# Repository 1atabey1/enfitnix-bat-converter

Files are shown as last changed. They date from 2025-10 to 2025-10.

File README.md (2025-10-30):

# ENFITNIX Battery Converter

Bike lights by Enfitnix use the quite common 18650 form factor for their batteries. However, they require a very specific protection PCB that exposes both poles of the battery in two concentric circles on one side.

It's kinda hard to get these batteries (at least in Europe -> over 30€ for a single [battery](https://de.grandado.com/products/enfitnix-navi800-fahrrad-licht-lg-3350mah-akku-integrierte-hohe-prazision-batterie)!!!), so this custom PCB offers the option of converting almost any 18650 battery into one that fits your bike light for a BOM cost of just around 1€.

## Order

Any non-basic part has an LCSC part number attached so you can directly upload the files from the latest [release](https://github.com/1atabey1/enfitnix-bat-converter/releases) to JLCPCB and order the fully assembled PCBs.

## Limitations

The current design is parametrised as follows

```
OVP: 4.2V
UVP: 2.5V
OCC: 18A
OCD: 40A
```

Before use, please confirm your cell's voltage range aligns with these limits (i.e. max cell operating voltage > OVP and min cell operating voltage < UVP). 

This will **not** work for LFP based cells!

## Usage

I recommend using heat shrink and a plastic base for the PCB as you get it from e.g. [AliExpress](https://de.aliexpress.com/item/32855964562.html)

With that the process is quite simple:
1. Solder one nickel strip each to the pads marked with + and -
2. Thread nickel strips through plastic base
3. Spot weld respective strips to their corresponding terminal of the cell
4. Wrap it all up in heat shrink

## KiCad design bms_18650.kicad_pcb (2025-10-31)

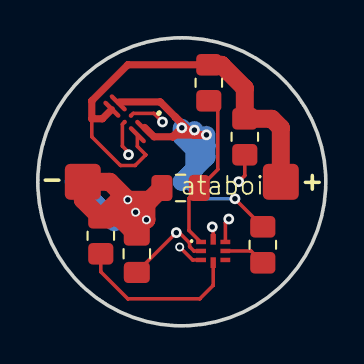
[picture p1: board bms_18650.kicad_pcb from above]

Board: 4 copper layers, 16.0 x 16.0 mm, 10 parts (0 on the bottom side), 9 nets.

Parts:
C1, C2: 0.1uF; C_0805_2012Metric_Pad1.18x1.45mm_HandSolder
IC1: BQ298218RUGR; ADS7056IRUGR
IC2: EFC8811R-TF; EFC8811RTF
J1: ENFITNIX_BAT
J2: CELL_LEAD_CONN
R3: 330; R_0805_2012Metric_Pad1.20x1.40mm_HandSolder
R4: 20; R_0805_2012Metric_Pad1.20x1.40mm_HandSolder
R5: 2k; R_0805_2012Metric_Pad1.20x1.40mm_HandSolder
R_SEN1: 0.001; R_0805_2012Metric_Pad1.20x1.40mm_HandSolder

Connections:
CELL+: IC2.4 (S2_1), IC2.6 (S2_2), J2.1 (CELL+), R3.2, R4.2
CELL-: C1.2, C2.1, IC1.3 (VSS), J1.2 (-), J2.2 (CELL-), R_SEN1.2
LINK+: IC2.1 (S1_1), IC2.3 (S1_2), J1.1 (+), R5.1
unnamed: C1.1, IC1.1 (BAT), R4.1
unnamed: IC1.8 (CHG), IC2.5 (G2)
unnamed: IC1.4 (CS), R_SEN1.1
unnamed: IC1.7 (DSG), IC2.2 (G1)
unnamed: IC1.6 (PACK), R5.2
unnamed: C2.2, IC1.2 (VDD), R3.1

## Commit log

2025-10-20 add initial files
    [bms_18650.kicad_pcb, bms_18650.kicad_sch]
2025-10-30 first ordered revision
    [bms_18650-B_Cu.gbr, bms_18650-B_Mask.gbr, bms_18650-B_Paste.gbr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]
2025-10-30 add readme
    [bms_18650-B_Cu.gbr, bms_18650-B_Mask.gbr, bms_18650-B_Paste.gbr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]
2025-10-31 no more blind vias
    [bms_18650.kicad_pcb]
2025-12-31 Update README with release note for version 1.0.0
    Added a note about the current release not being functional without workarounds.
2026-01-06 fix footprint
    fixes issue #1
